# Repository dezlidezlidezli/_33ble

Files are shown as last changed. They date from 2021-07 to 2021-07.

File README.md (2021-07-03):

# _33BLE
A bluetooth drop-in PCB for the [_33 keyboard](https://github.com/tominabox1/_33-Keyboard) by [tominabox1](https://github.com/tominabox1). Documentation is available [here](https://dez.li/_33ble), and the ZMK config repository is available [here](https://github.com/dezlidezlidezli/underscore33-zmk-config). 

The board can be produced at [JLCPCB](jlcpcb.com) for rather cheap, and through their PCBA service they will assemble every component other than the the [Holyiot 18010 module](https://www.aliexpress.com/item/32868002366.html). You'll need to purchase this seperately, and solder it. Files for this can be found in the Production Files directory, when ordering make sure to choose "assemble bottom side" and tooling holes aded by JLCPCB. 

You'll also need to flash the bootloader to the Holyiot module. The bootloader file can be found [here](/underscore33_bootloader.hex), and should be flashed using an ST-Link V2 clone, or a J-Link. Details for how to do this are available on the nice!keyboards wiki, and on the nRFMicro wiki. Please note that the Holyiot module does not need to be unlocked. 

Alternatively, you can choose to export files suited for another manufacturer, such as Elecrow or PCBWay, where they will assemble the entire board. Some manufacturers may also be able to flash the bootloader in their factory, so this may be worth asking your customer support representative. 

Thank you to [Makenova](https://github.com/makenova) and [Matthew Dias](https://github.com/matthewdias) for funding the open-sourcing of this project.

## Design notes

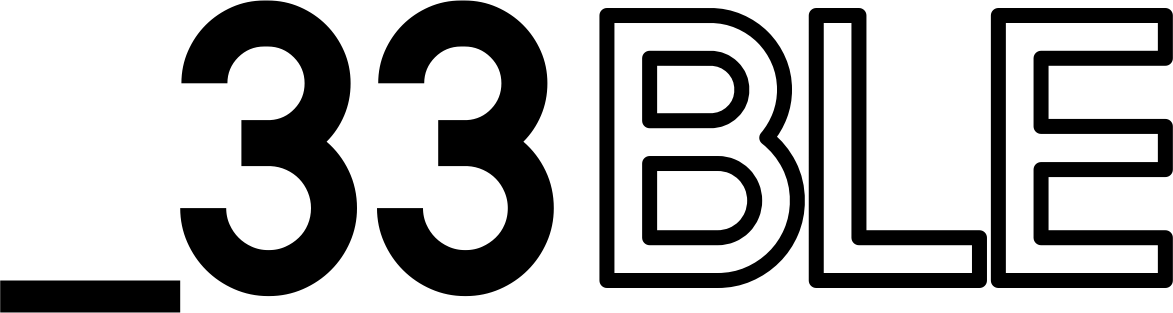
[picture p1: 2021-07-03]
PCB Art/silk.png

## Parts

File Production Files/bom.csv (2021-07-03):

Comment | Designator | Footprint | LCSC Part #（optional）
SW_SPST | SW41 | SW-SMD-4_5.2x5.2x3.7P | C92584
SR05 | D2 | SOT-143 | C384891
BAV70 | D8,D22,D21,D20,D19,D18,D17,D16,D15,D14,D13,D12,D11,D10,D9,D7,D6,D5 | SOT-23 | C68978
4.7n | C4 | C_0805_2012Metric | C1744
SW_SPDT | SW37 | SMD-7PIN | C109335
HRO-TYPE-C-31-M-12 | USB1 | TYPE-C-31_L8.94_W7.3 | C165948
TP4054 | U2 | SOT-23-5 | C32574
AP2112K-3.3 | U1 | SOT-23-5 | C51118
1k | R9 | R_0805_2012Metric | C17513
2M | R8 | R_0805_2012Metric | C26112
806k | R7 | R_0805_2012Metric | C63494
1M | R6 | R_0805_2012Metric | C17514
5.1k | R5,R1 | R_0805_2012Metric | C27834
10k | R3,R2 | R_0805_2012Metric | C17414
AO3401A | Q1 | SOT-23 | C306862
500ma | F1 | Fuse_1206_3216Metric | C70076
LED_Small | D4 | D_0805_2012Metric | C2296
1N5819 | D1 | D_SOD-123 | C169540
1uF | C3,C2 | C_0805_2012Metric | C28323
4.7uF | C1 | C_0805_2012Metric | C1779
Battery_Cell | BT1 | CONN-TH_A2001WR-2P | C225207

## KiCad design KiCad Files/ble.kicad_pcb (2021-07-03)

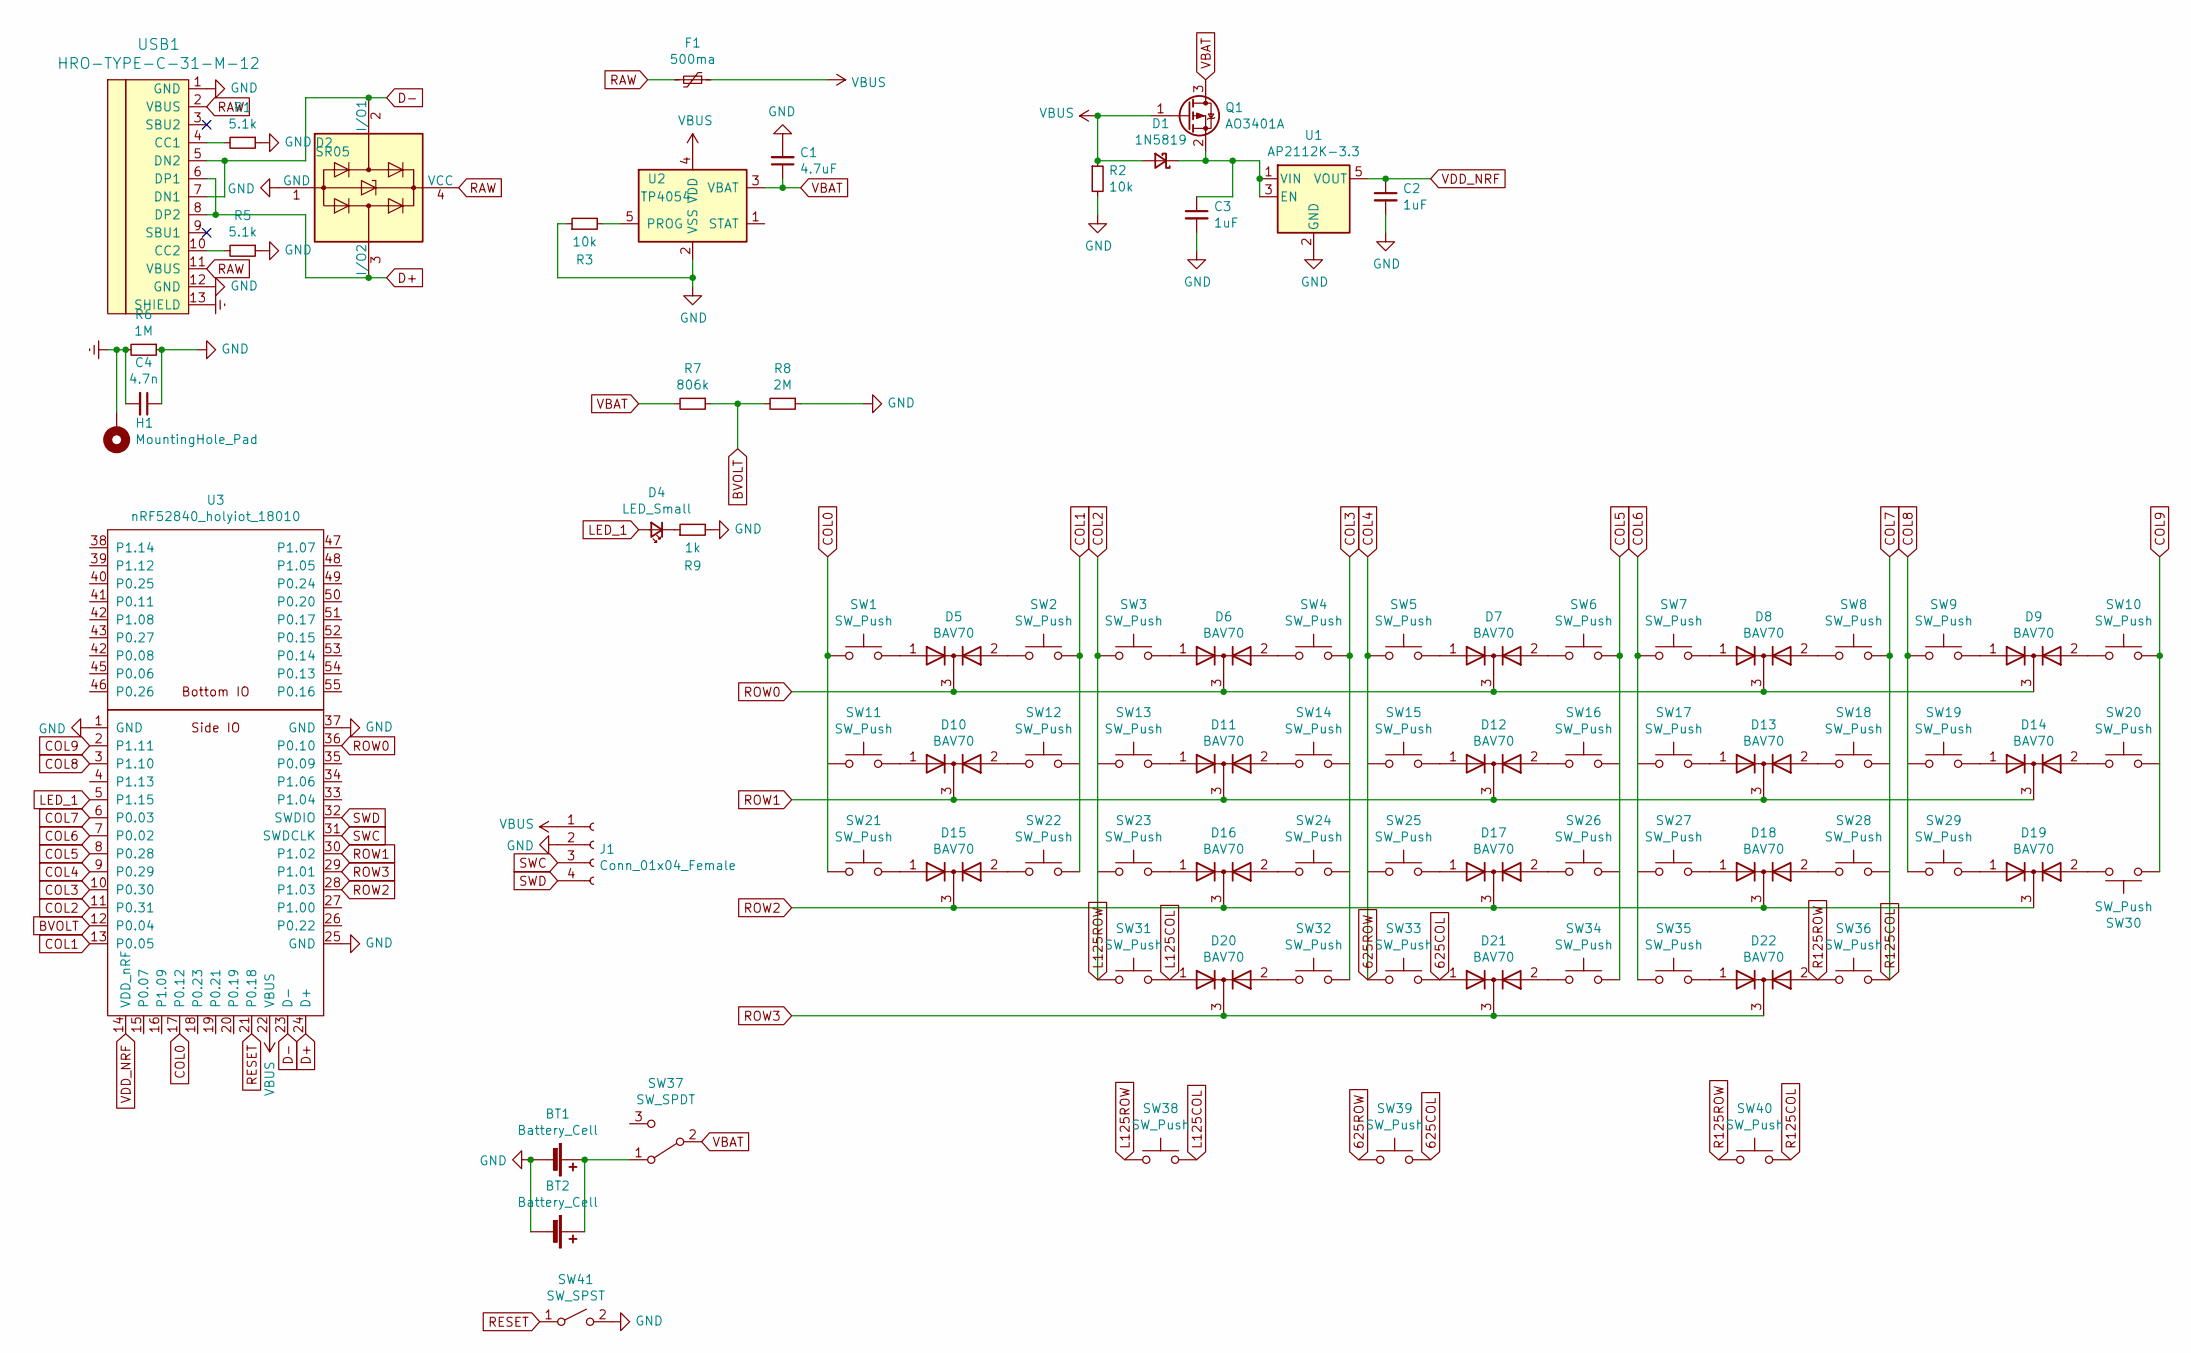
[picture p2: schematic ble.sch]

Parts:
BT1: Battery_Cell; JST_PH_S2B-PH-K_1x02_P2.00mm_Horizontal
BT2: Battery_Cell; custombatteryconnector
C1: 4.7uF; C_0805_2012Metric
C2, C3: 1uF; C_0805_2012Metric
C4: 4.7n; C_0805_2012Metric
D1: 1N5819; D_SOD-123
D2: SR05; SOT-143
D4: LED_Small; D_0805_2012Metric
D5, D6, D7, D8, D9, D10, D11, D12, D13, D14, D15, D16, D17, D18, D19, D20, D21, D22: BAV70; SOT-23
F1: 500ma; Fuse_1206_3216Metric
H1: MountingHole_Pad
J1: Conn_01x04_Female; PinSocket_1x04_P2.54mm_Vertical
Q1: AO3401A; SOT-23
R1, R5: 5.1k; R_0805_2012Metric
R2, R3: 10k; R_0805_2012Metric
R6: 1M; R_0805_2012Metric
R7: 806k; R_0805_2012Metric
R8: 2M; R_0805_2012Metric
R9: 1k; R_0805_2012Metric
SW1, SW2, SW3, SW4, SW5, SW6, SW7, SW8, SW9, SW10, SW11, SW12, SW13, SW14, SW15, SW16, SW17, SW18, SW19, SW20, SW21, SW22, SW23, SW24, SW25, SW26, SW27, SW28, SW29, SW30, SW31, SW36: SW_Push; MXOnly-1U-NoLED
SW32, SW35, SW38, SW40: SW_Push; MXOnly-1.25U-NoLED
SW33: SW_Push; MXOnly-2.25U-ReversedStabilizers-NoLED
SW34: SW_Push; MXOnly-2U-ReversedStabilizers-NoLED
SW37: SW_SPDT; SW_SPDT_PCM12
SW39: SW_Push; MXOnly-6.25U-ReversedStabilizers-NoLED
SW41: SW_SPST; SW_SPST_TL3342
U1: AP2112K-3.3; SOT-23-5
U2: TP4054; SOT-23-5
U3: nRF52840_holyiot_18010
USB1: HRO-TYPE-C-31-M-12; HRO-TYPE-C-31-M-12-HandSoldering

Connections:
625COL: D21.1 (A), SW33.2, SW39.2
625ROW: SW5.1, SW15.1, SW25.1, SW33.1, SW39.1, U3.9 (P0.29)
BVOLT: R7.1, R8.2, U3.12 (P0.04)
COL0: SW1.1, SW11.1, SW21.1, U3.17 (P0.12)
COL1: SW2.2, SW12.2, SW22.2, U3.13 (P0.05)
COL2: SW3.1, SW13.1, SW23.1, SW31.1, SW38.1, U3.11 (P0.31)
COL3: SW4.2, SW14.2, SW24.2, SW32.2, U3.10 (P0.30)
COL5: SW6.2, SW16.2, SW26.2, SW34.2, U3.8 (P0.28)
COL6: SW7.1, SW17.1, SW27.1, SW35.1, U3.7 (P0.02)
COL7: SW8.2, SW18.2, SW28.2, SW36.2, SW40.2, U3.6 (P0.03)
COL8: SW9.1, SW19.1, SW29.1, U3.3 (P1.10)
COL9: SW10.2, SW20.2, SW30.1, U3.2 (P1.11)
D+: D2.3 (I/O2), U3.24 (D+), USB1.6 (DP1), USB1.8 (DP2)
D-: D2.2 (I/O1), U3.23 (D-), USB1.5 (DN2), USB1.7 (DN1)
Earth: C4.2, H1.1, R6.2, USB1.13 (SHIELD)
GND: BT1.2 (-), BT2.2 (-), C1.2, C2.2, C3.2, C4.1, D2.1 (GND), J1.2, R1.1, R2.2, R3.1, R5.1, R6.1, R8.1, R9.2, SW41.2 (B), U1.2 (GND), U2.2 (VSS), U3.1 (GND), U3.25 (GND), U3.37 (GND), USB1.1 (GND), USB1.12 (GND)
L125COL: D20.1 (A), SW31.2, SW38.2
LED_1: D4.2 (A), U3.5 (P1.15)
unnamed: BT1.1 (+), BT2.1 (+), SW37.1 (A)
unnamed: C3.1, D1.1 (K), Q1.2 (S), U1.1 (VIN), U1.3 (EN)
unnamed: D4.1 (K), R9.1
unnamed: D5.1 (A), SW1.2
unnamed: D5.2 (A), SW2.1
unnamed: D6.1 (A), SW3.2
unnamed: D6.2 (A), SW4.1
unnamed: D7.1 (A), SW5.2
unnamed: D7.2 (A), SW6.1
unnamed: D8.1 (A), SW7.2
unnamed: D8.2 (A), SW8.1
unnamed: D9.1 (A), SW9.2
unnamed: D9.2 (A), SW10.1
unnamed: D10.1 (A), SW11.2
unnamed: D10.2 (A), SW12.1
unnamed: D11.1 (A), SW13.2
unnamed: D11.2 (A), SW14.1
unnamed: D12.1 (A), SW15.2
unnamed: D12.2 (A), SW16.1
unnamed: D13.1 (A), SW17.2
unnamed: D13.2 (A), SW18.1
unnamed: D14.1 (A), SW19.2
unnamed: D14.2 (A), SW20.1
unnamed: D15.1 (A), SW21.2
unnamed: D15.2 (A), SW22.1
unnamed: D16.1 (A), SW23.2
unnamed: D16.2 (A), SW24.1
unnamed: D17.1 (A), SW25.2
unnamed: D17.2 (A), SW26.1
unnamed: D18.1 (A), SW27.2
unnamed: D18.2 (A), SW28.1
unnamed: D19.1 (A), SW29.2
unnamed: D19.2 (A), SW30.2
unnamed: D20.2 (A), SW32.1
unnamed: D21.2 (A), SW34.1
unnamed: D22.1 (A), SW35.2
unnamed: R1.2, USB1.4 (CC1)
unnamed: R3.2, U2.5 (PROG)
unnamed: R5.2, USB1.10 (CC2)
R125ROW: D22.2 (A), SW36.1, SW40.1
RAW: D2.4 (VCC), F1.2, USB1.2 (VBUS), USB1.11 (VBUS)
RESET: SW41.1 (A), U3.21 (P0.18)
ROW0: D5.3 (K), D6.3 (K), D7.3 (K), D8.3 (K), D9.3 (K), U3.36 (P0.10)
ROW1: D10.3 (K), D11.3 (K), D12.3 (K), D13.3 (K), D14.3 (K), U3.30 (P1.02)
ROW2: D15.3 (K), D16.3 (K), D17.3 (K), D18.3 (K), D19.3 (K), U3.28 (P1.03)
ROW3: D20.3 (K), D21.3 (K), D22.3 (K), U3.29 (P1.01)
SWC: J1.3, U3.31 (SWDCLK)
SWD: J1.4, U3.32 (SWDIO)
VBAT: C1.1, Q1.3 (D), R7.2, SW37.2 (B), U2.3 (VBAT)
VBUS: D1.2 (A), F1.1, J1.1, Q1.1 (G), R2.1, U2.4 (VDD), U3.22 (VBUS)
VDD_NRF: C2.1, U1.5 (VOUT), U3.14 (VDD_nRF)

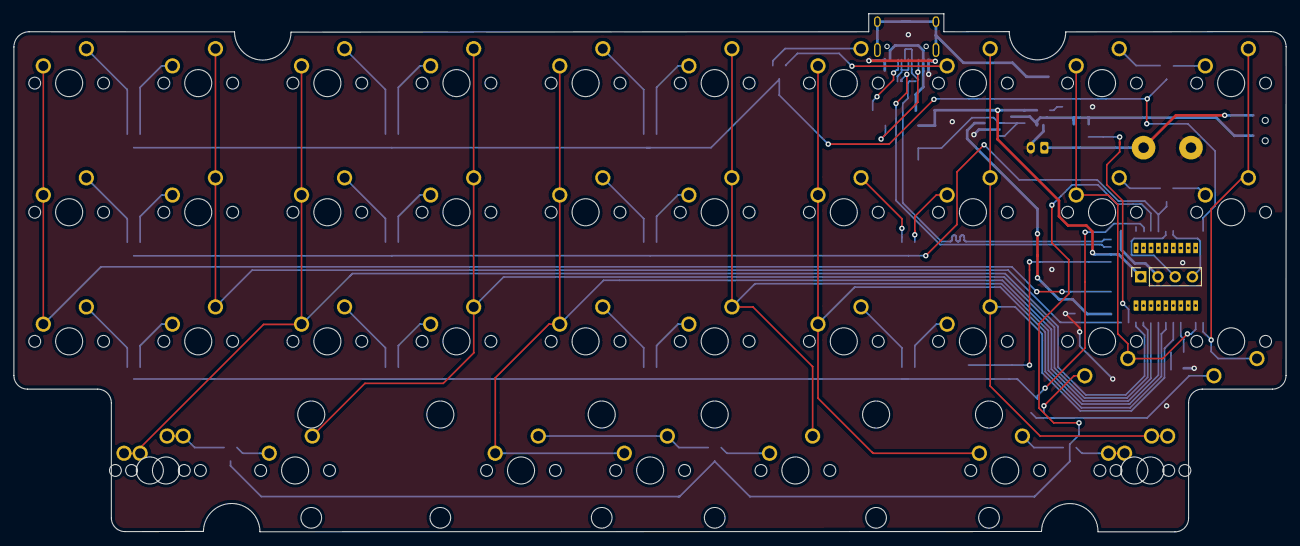
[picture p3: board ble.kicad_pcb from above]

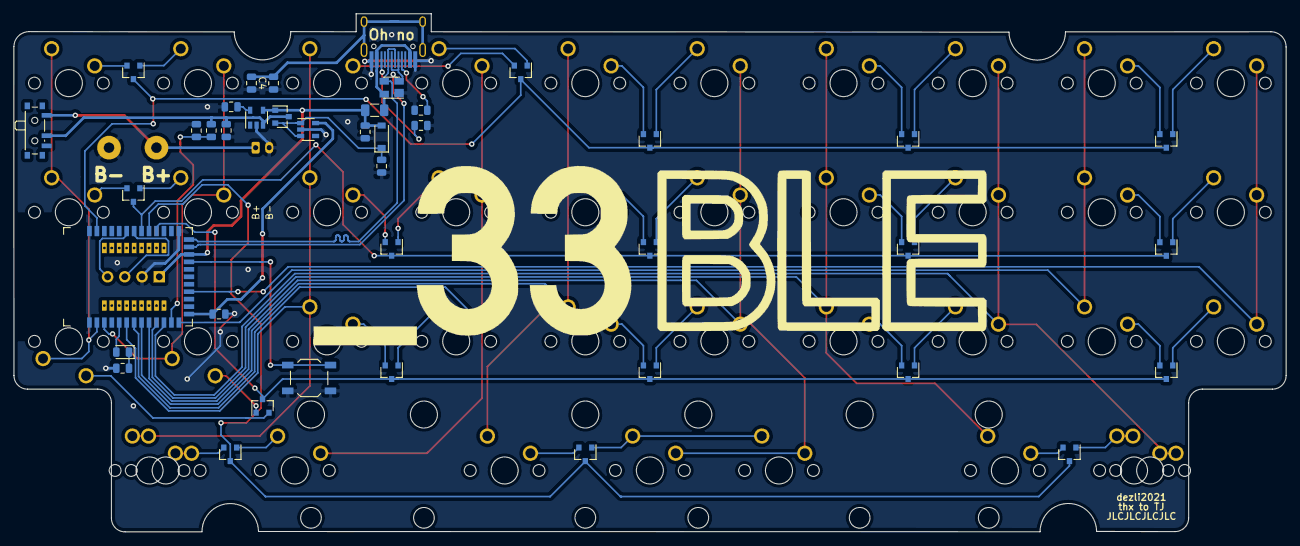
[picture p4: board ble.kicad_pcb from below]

Board: 2 copper layers, 187.7 x 76.4 mm, 83 parts (43 on the bottom side), 69 nets.
